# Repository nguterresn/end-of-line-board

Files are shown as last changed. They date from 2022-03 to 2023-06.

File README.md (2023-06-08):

## End Of Line Board for Testing

FO4LOj3WUAYNTAF?format=jpg name=large

### Quick Introduction

Normally, in the world of _access control_, a [contact sensor](https://www.gensecurity.com/blog/how-do-contatct-sensors-work) is either open or closed. This is essentially true if the system does not support **end of line**.
End of line increases the number of avaialble _states_ of a contact sensor, from two to four:

| Opened | Closed | (new) Shorted | (new) Cut |
|---|---|---|-----|

This is very important in Alarm and Fire systems, where these four states are essential.

### Board

This design aims to test all the possible configurations for end of line: 

| | **Single Resistor Line Shorted** | **Single Resistor Line Cut** | **Double Resistor** |
|---|:---:|:---:|:---:|
| **Opened**  | ✅ | ✅ | ✅ |
| **Closed**  | ✅ | ✅ | ✅ |
| **Shorted** | ✅ | ❌ | ✅ |
| **Cut** | ❌ | ✅ | ✅ |

There a is good [document here](https://github.com/nguterresn/end-of-line-board/blob/master/docs/EOL-Types.pdf) explaining the difference between configurations.

### 3D View



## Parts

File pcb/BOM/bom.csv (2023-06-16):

Comment | Designator | Footprint | LCSC
MountingHole | H1,H2,H3,H4 | MountingHole:MountingHole_3.2mm_M3_Pad_Via
Conn_01x06 | J1 | TerminalBlock_Phoenix:TerminalBlock_Phoenix_MKDS-1,5-6_1x06_P5.00mm_Horizontal | C2802619
2k2 | R1,R2,R3 | Resistor_SMD:R_0603_1608Metric_Pad1.05x0.95mm_HandSolder | C5140136
1k | R4 | Resistor_SMD:R_0603_1608Metric_Pad1.05x0.95mm_HandSolder | C3152127
Slide_DPDT | SW1,SW2,SW3,SW4 | Button_Switch_THT:SW_E-Switch_EG1271_DPDT | C2906278
SW_Push_DPDT | SW5,SW6,SW7 | External:MHPS2285 | C493261

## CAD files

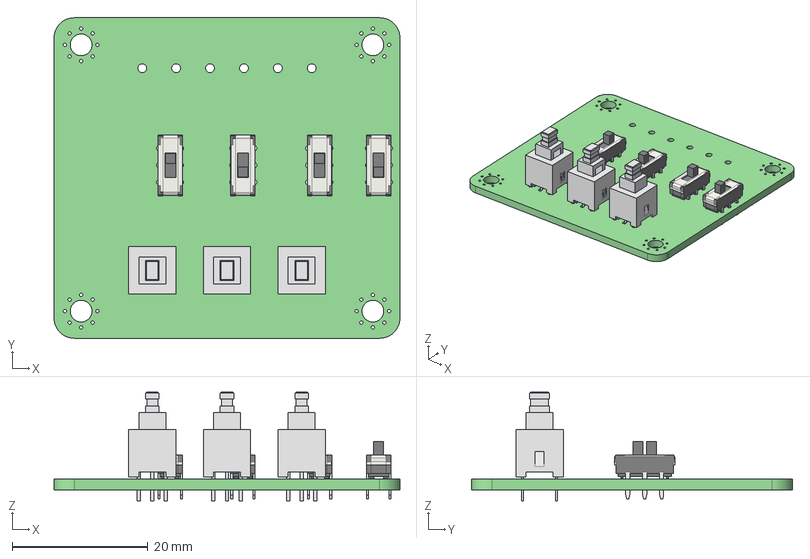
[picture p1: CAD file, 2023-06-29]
stl/EOL.step
51.0 x 47.2 x 16.0 mm
EOL PCB

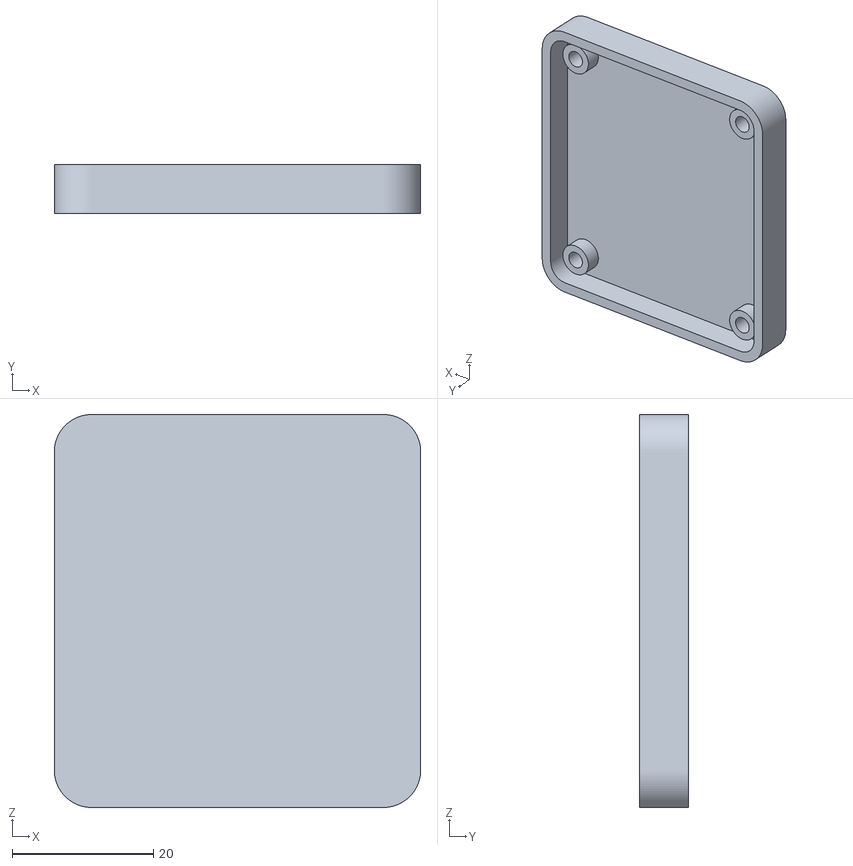
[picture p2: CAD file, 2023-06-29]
stl/box.stl
51.8 x 7.00 x 55.6

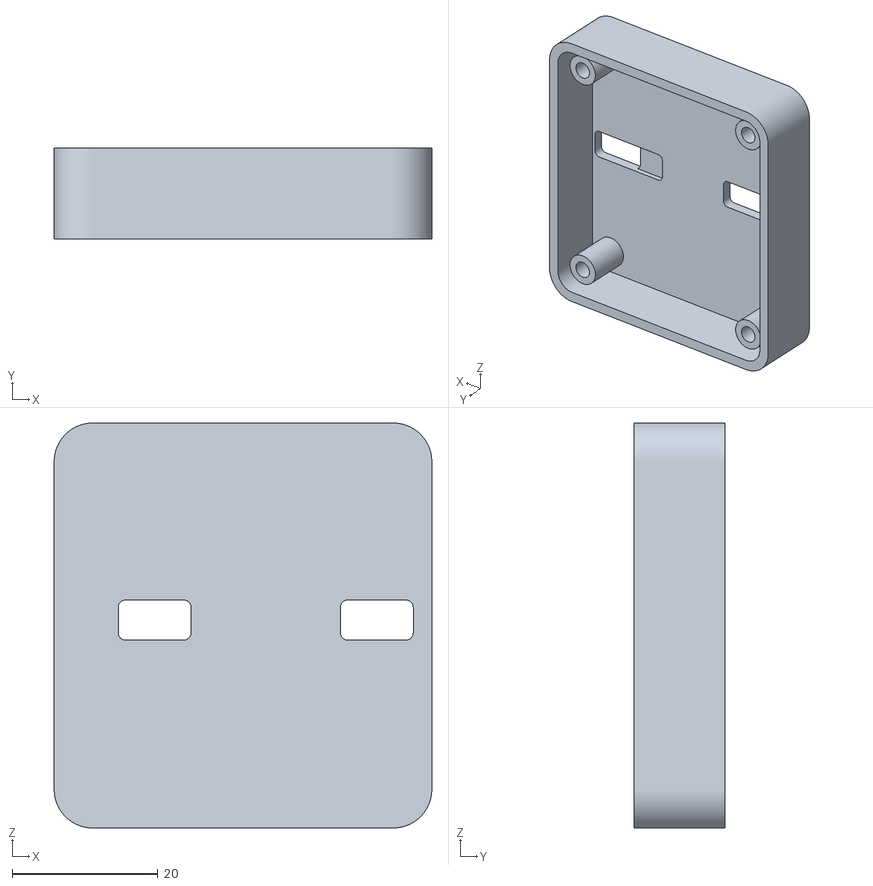
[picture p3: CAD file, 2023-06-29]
stl/box_skadis.stl
51.8 x 12.5 x 55.6

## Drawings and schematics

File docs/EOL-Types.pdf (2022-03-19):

## Single Resistor Line Shorted

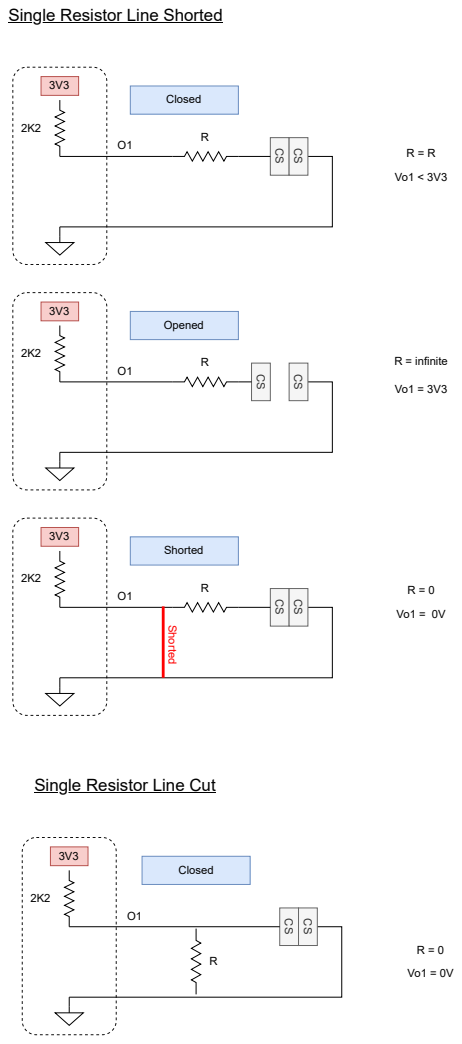
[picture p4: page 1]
R = infinite; Shorted; Closed; Opened

Single Resistor Line Cut

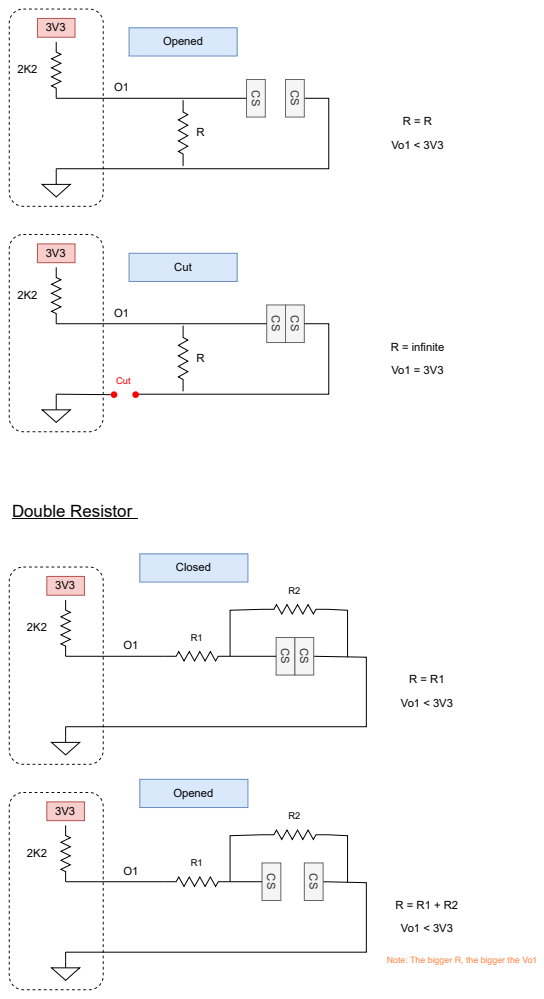
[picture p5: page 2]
Opened; R = infinite; Cut; Double Resistor; Closed

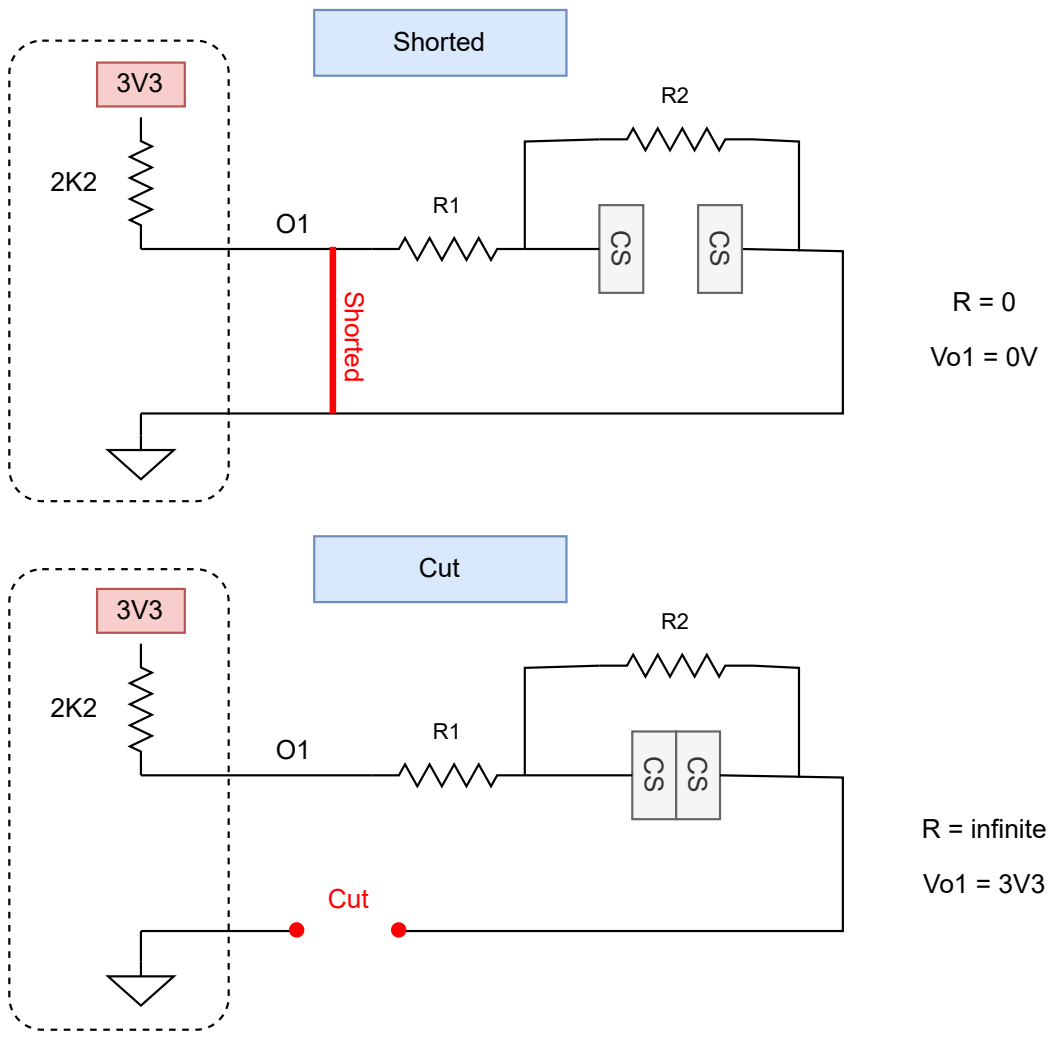
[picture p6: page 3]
Shorted; R = infinite Vo1 = 3V3; Cut

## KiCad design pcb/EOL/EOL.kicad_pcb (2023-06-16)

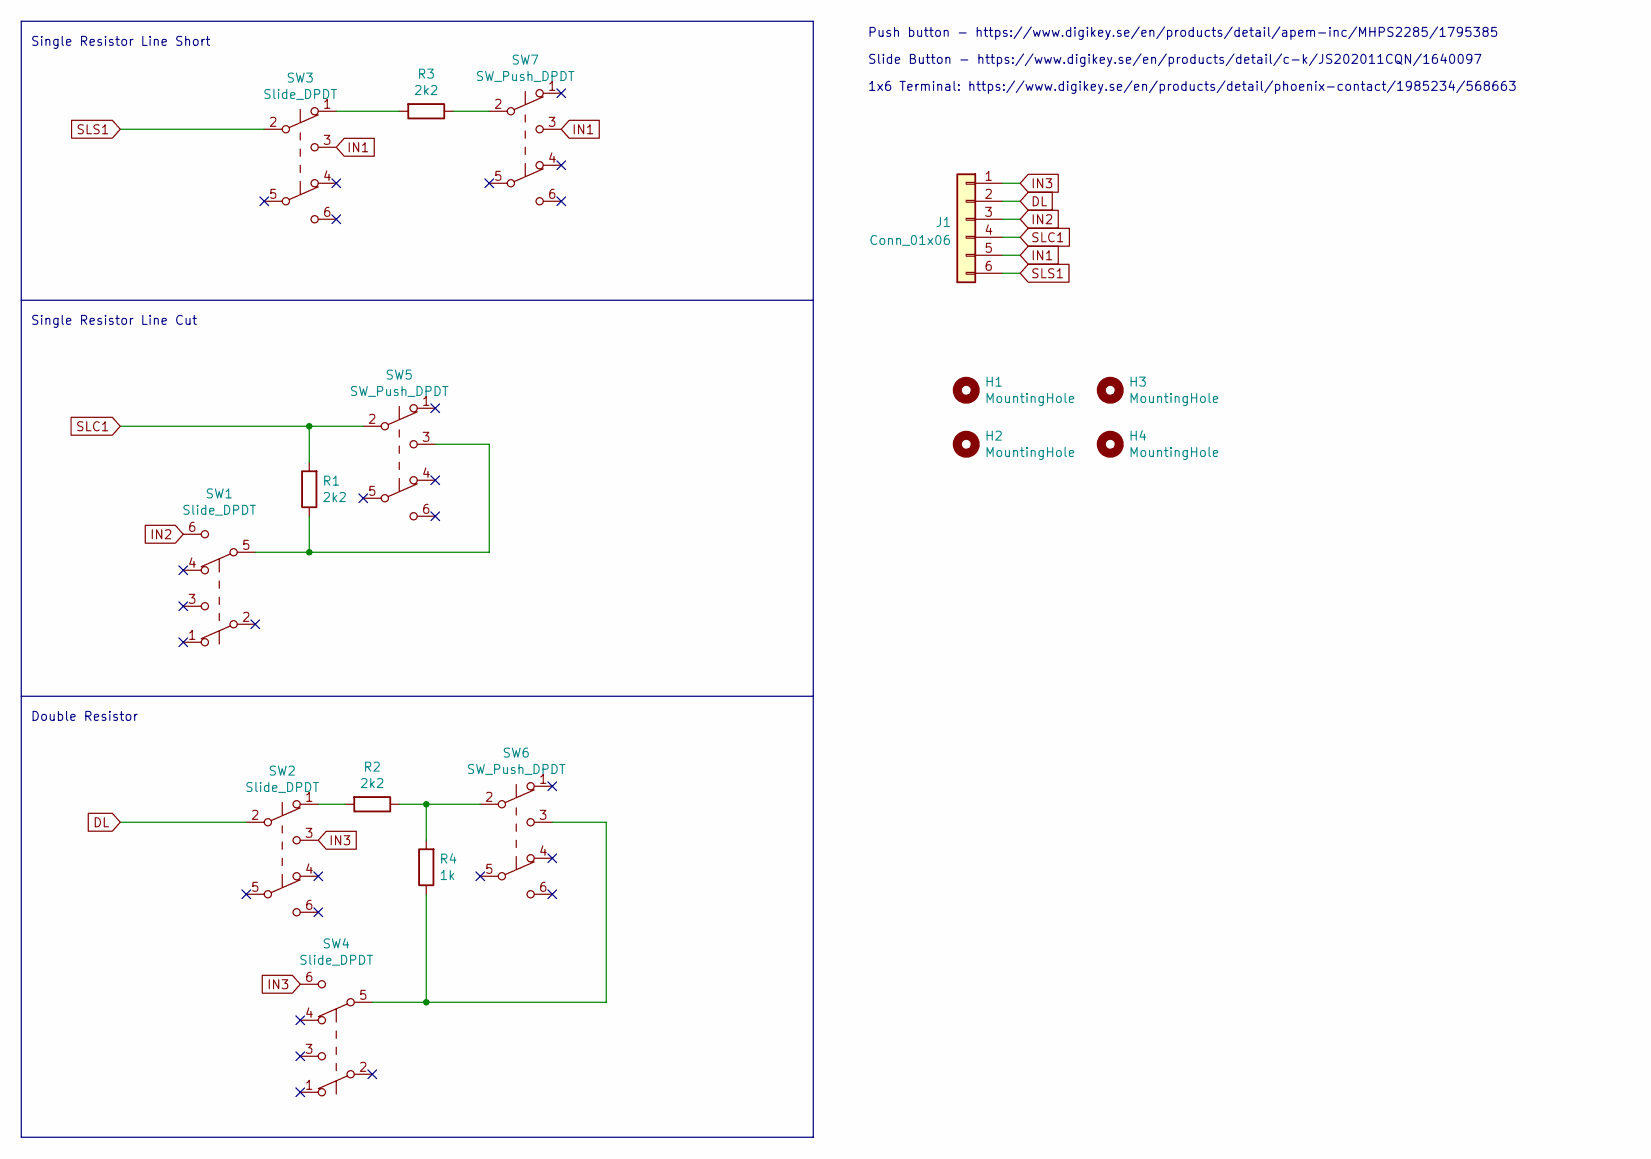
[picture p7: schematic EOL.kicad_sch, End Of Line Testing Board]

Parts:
H1, H2, H3, H4: MountingHole; MountingHole_3.2mm_M3_Pad_Via
J1: Conn_01x06; TerminalBlock_Phoenix_MKDS-1,5-6_1x06_P5.00mm_Horizontal; LCSC C2802619
R1, R2, R3: 2k2; R_0603_1608Metric_Pad1.05x0.95mm_HandSolder; LCSC C5140136
R4: 1k; R_0603_1608Metric_Pad1.05x0.95mm_HandSolder; LCSC C3152127
SW1, SW2, SW3, SW4: Slide_DPDT; SW_E-Switch_EG1271_DPDT; LCSC C2906278
SW5, SW6, SW7: SW_Push_DPDT; MHPS2285; LCSC C493261

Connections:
DL: J1.2, SW2.2 (B)
IN1: J1.5, SW3.3 (C), SW7.3 (C)
IN2: J1.3, SW1.6 (C)
IN3: J1.1, SW2.3 (C), SW4.6 (C)
unnamed: R1.1, SW1.5 (B), SW5.3 (C)
unnamed: R2.1, R4.2, SW6.2 (B)
unnamed: R2.2, SW2.1 (A)
unnamed: R3.1, SW7.2 (B)
unnamed: R3.2, SW3.1 (A)
unnamed: R4.1, SW4.5 (B), SW6.3 (C)
SLC1: J1.4, R1.2, SW5.2 (B)
SLS1: J1.6, SW3.2 (B)

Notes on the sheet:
1x6 Terminal: https://www.digikey.se/en/products/detail/phoenix-contact/1985234/568663
Push button - https://www.digikey.se/en/products/detail/apem-inc/MHPS2285/1795385
Single Resistor Line Cut
Slide Button - https://www.digikey.se/en/products/detail/c-k/JS202011CQN/1640097
Single Resistor Line Short
Double Resistor

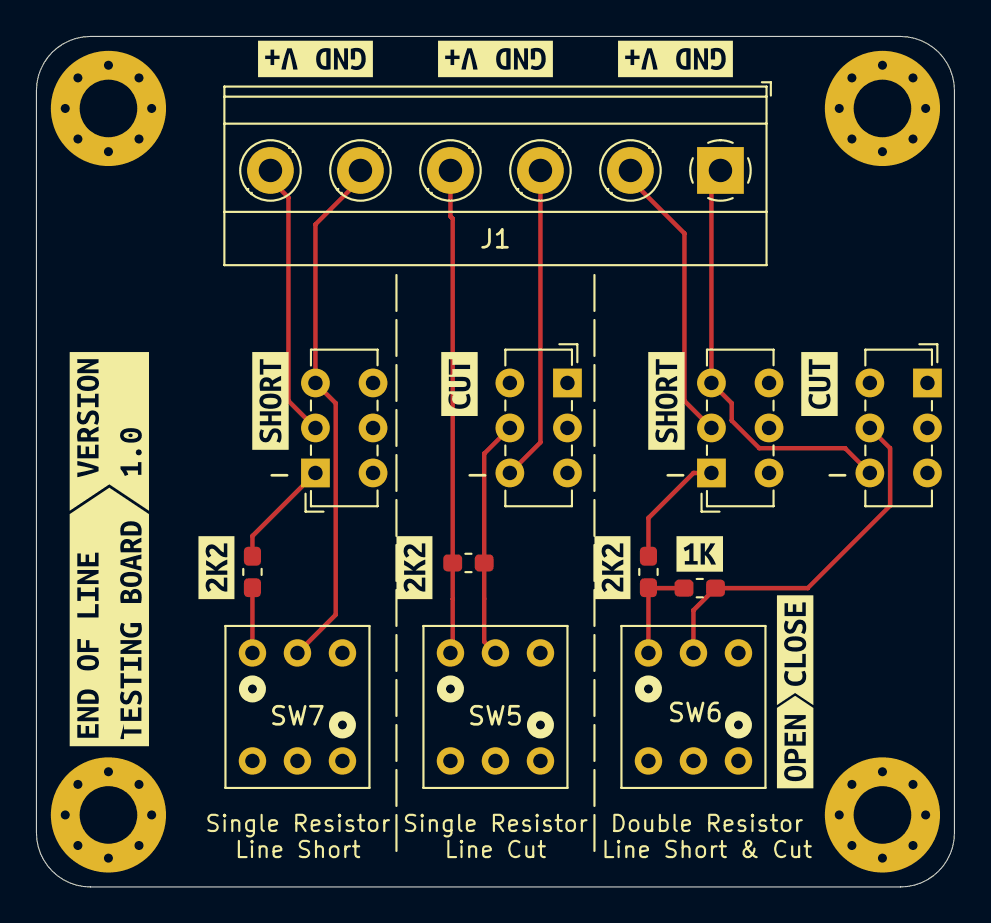
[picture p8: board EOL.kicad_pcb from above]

Board: 2 copper layers, 51.0 x 47.2 mm, 31 parts (0 on the bottom side), 12 nets.

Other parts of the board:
kibuzzard-6481E1FA, kibuzzard-6481E1FA#2: G***; kibuzzard-6481E1FA
kibuzzard-6481E2B4: G***; kibuzzard-6481E2B4
kibuzzard-6481E2F6, kibuzzard-6481E2F6#2, kibuzzard-6481E2F6#3: G***; kibuzzard-6481E2F6
kibuzzard-6481E3F6: G***; kibuzzard-6481E3F6
kibuzzard-6481E4F7: G***; kibuzzard-6481E4F7
kibuzzard-6481E55F: G***; kibuzzard-6481E55F
kibuzzard-6481E268, kibuzzard-6481E268#2: G***; kibuzzard-6481E268
kibuzzard-6481E412: G***; kibuzzard-6481E412
kibuzzard-6482D2A7, kibuzzard-6482D2A7#2, kibuzzard-6482D2A7#3: G***; kibuzzard-6482D2A7

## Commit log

2022-03-19 New docs and first steps into the pcb
    [EOL.kicad_pcb, EOL.sch]
2022-03-19 v1.0 of the End of line board
    [EOL-B_Cu.gbr, EOL-B_Mask.gbr, EOL-B_Paste.gbr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]
2022-04-06 Changed from screw terminal to push terminals
    [EOL.kicad_pcb, EOL.kicad_sch]
2022-04-06 New 3d model, transition to kicad v6
    [EOL.kicad_pcb]
2022-04-06 Minor changes.
    [EOL.kicad_pcb]
2022-04-06 Update sch.
    [EOL.kicad_sch]
2022-04-12 New design
    [EOL.kicad_pcb]
2022-04-17 Remove some unused files.
    [Holder_v0.1.stl]
2022-08-13 Deleted unused files.
    [EOL.kicad_pcb, EOL.sch]
2023-06-08 Updated Board labels. Made them bigger 👁️
    [EOL.kicad_pcb]
2023-06-09 Replace the terminal footprint for a screw terminal. Added the LCSC unique ids to ease the process of ordering a pcb.
    [EOL.kicad_pcb, EOL.kicad_sch]
2023-06-16 Added BOM , drill and gerber.
    [EOL-B_Cu.gbr, EOL-B_Mask.gbr, EOL-B_Paste.gbr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]
2023-06-29 box with ikea skadis support
    [EOL.step, box.stl, box_skadis.stl]
